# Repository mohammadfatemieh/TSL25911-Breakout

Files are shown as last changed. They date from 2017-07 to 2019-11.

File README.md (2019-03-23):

# TSL25911-Breakout
Breakout with AMS TSL25911 Digital Light Sensor.

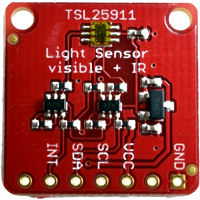
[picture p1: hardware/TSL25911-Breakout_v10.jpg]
TSL25911-Breakout


* [AMS TSL25911](https://ams.com/TSL25911) Light Sensor
* Detects visible and IR light
* Range: 0.5 lux to 88k lux
* TWI/I2C Interface (address 0x29)
* 3.3V - 5V Power Supply and Logic Level
* Open-Source and released under the [Creative Commons Attribution Share-Alike License](https://creativecommons.org/licenses/by-sa/4.0/).
* **[Documentation on learn.watterott.com](https://learn.watterott.com)**

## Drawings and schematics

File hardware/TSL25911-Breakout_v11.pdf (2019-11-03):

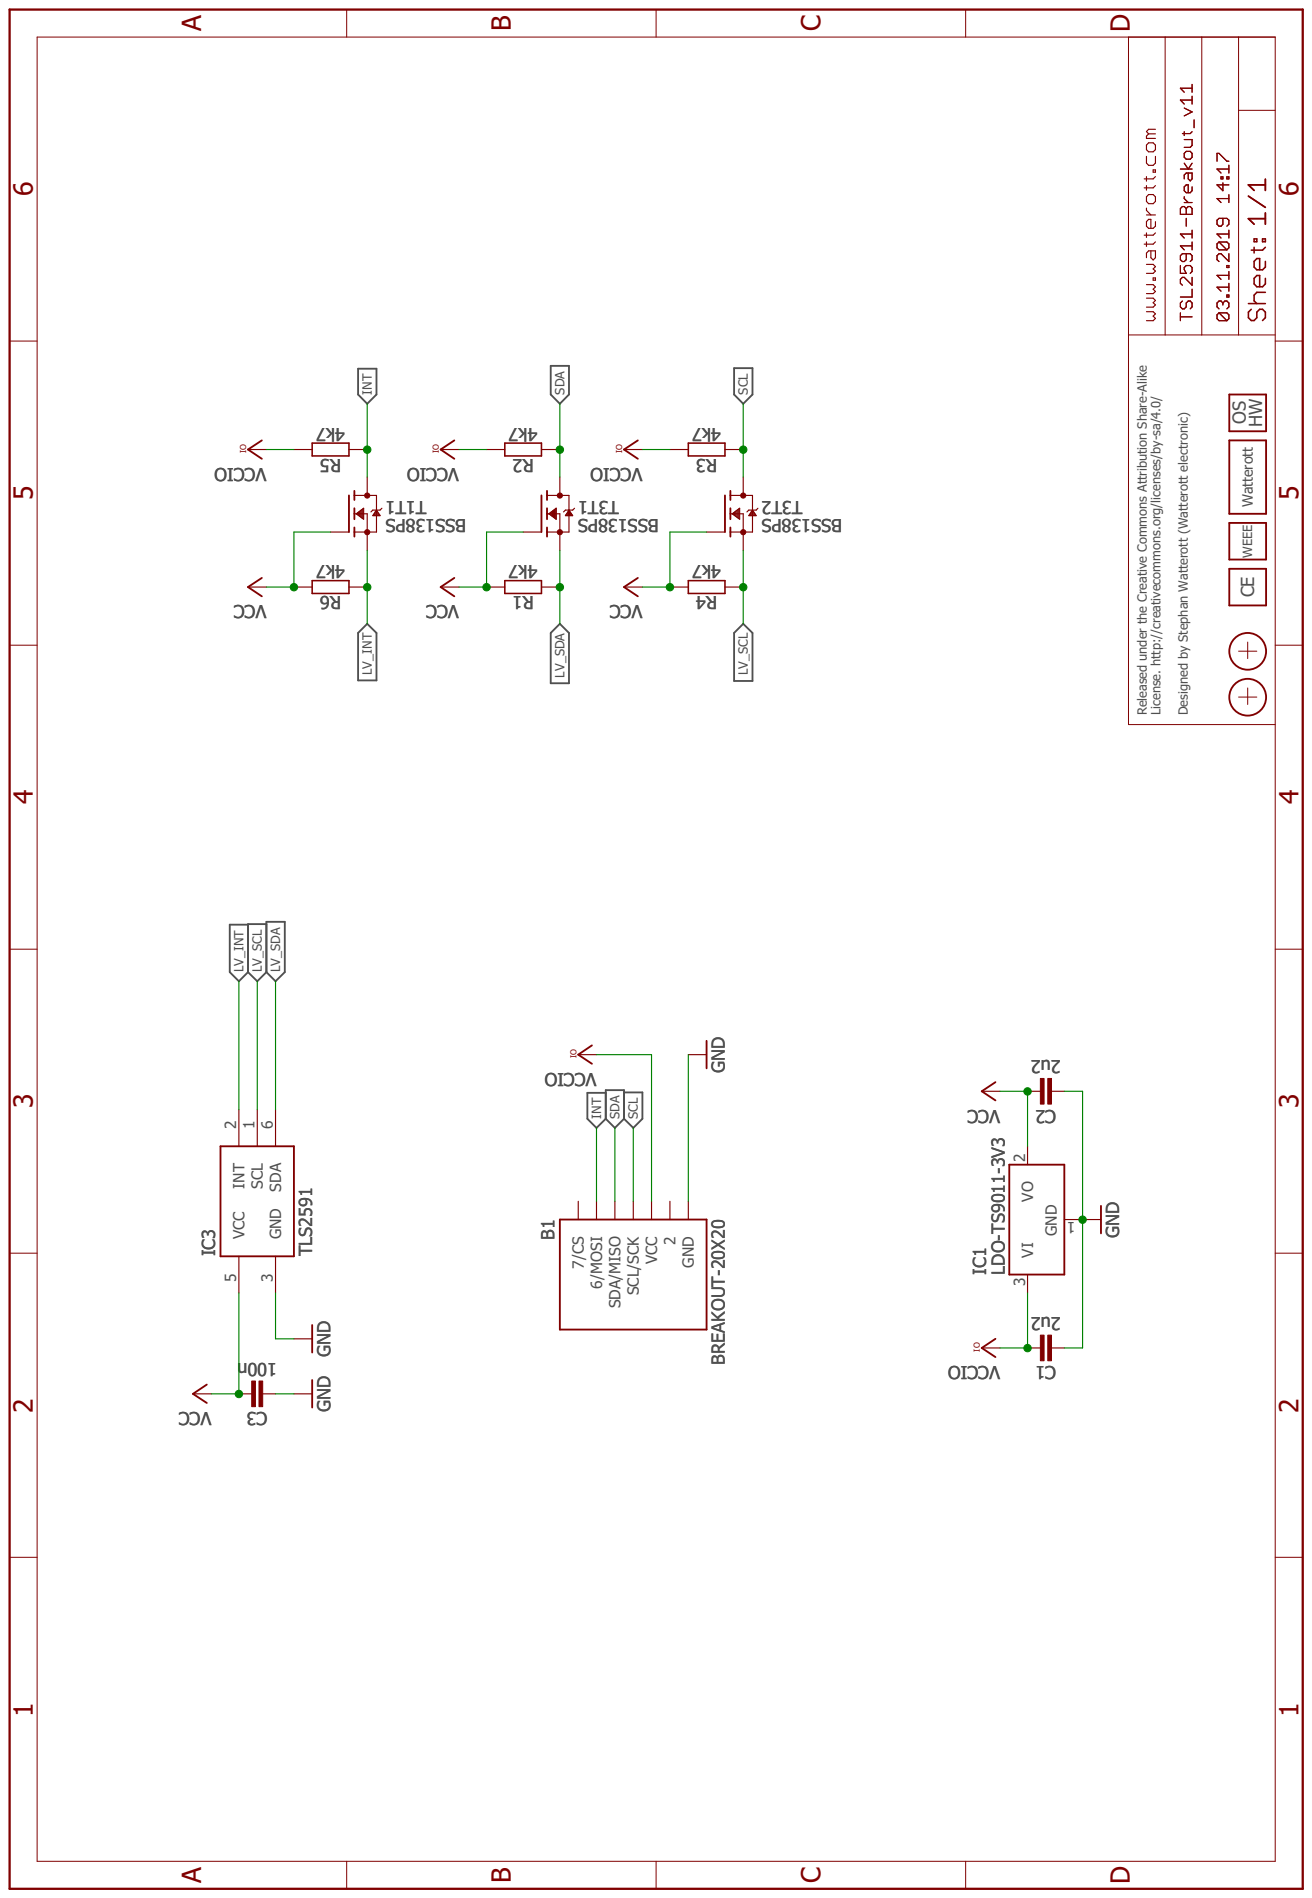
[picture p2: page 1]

Released under the Creative Commons Attribution Share-Alike

License. http://creativecommons.org/licenses/by-sa/4.0/ Designed by Stephan Watterott (Watterott electronic)

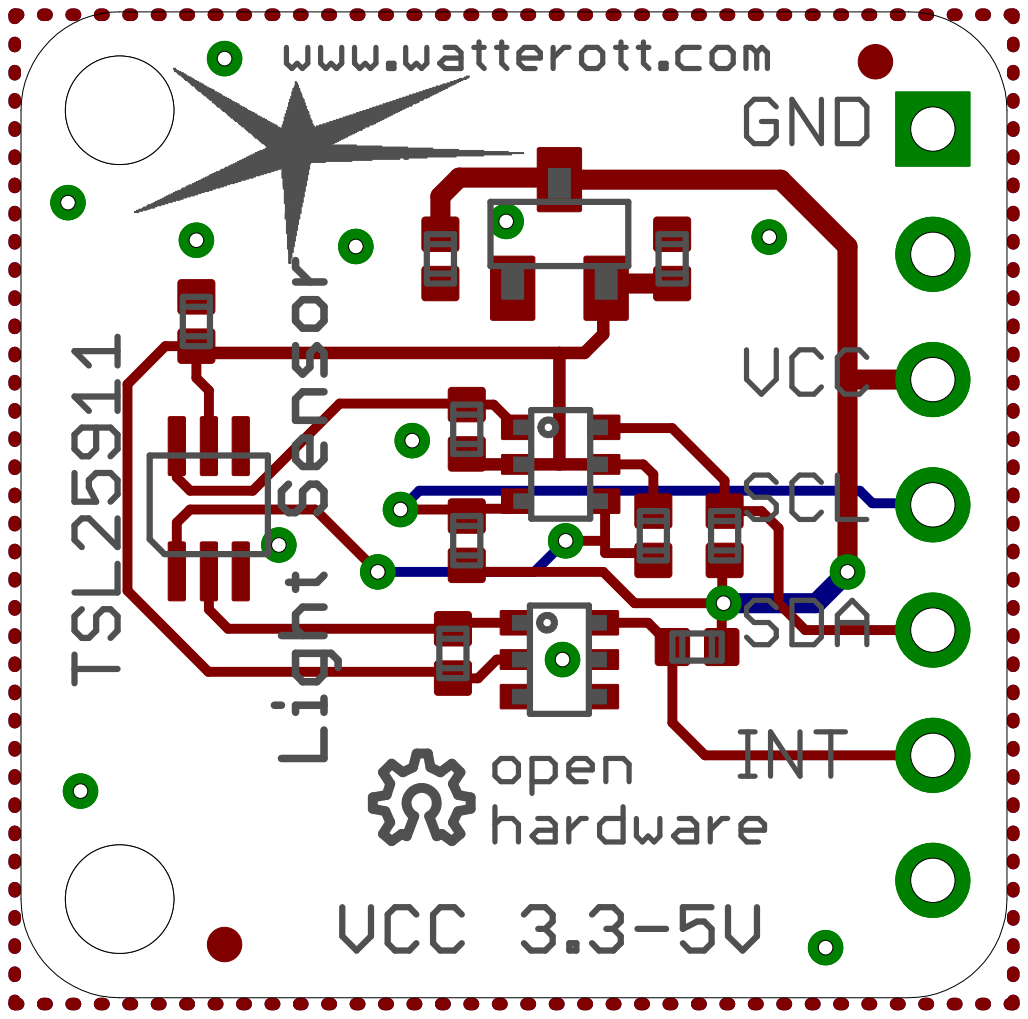
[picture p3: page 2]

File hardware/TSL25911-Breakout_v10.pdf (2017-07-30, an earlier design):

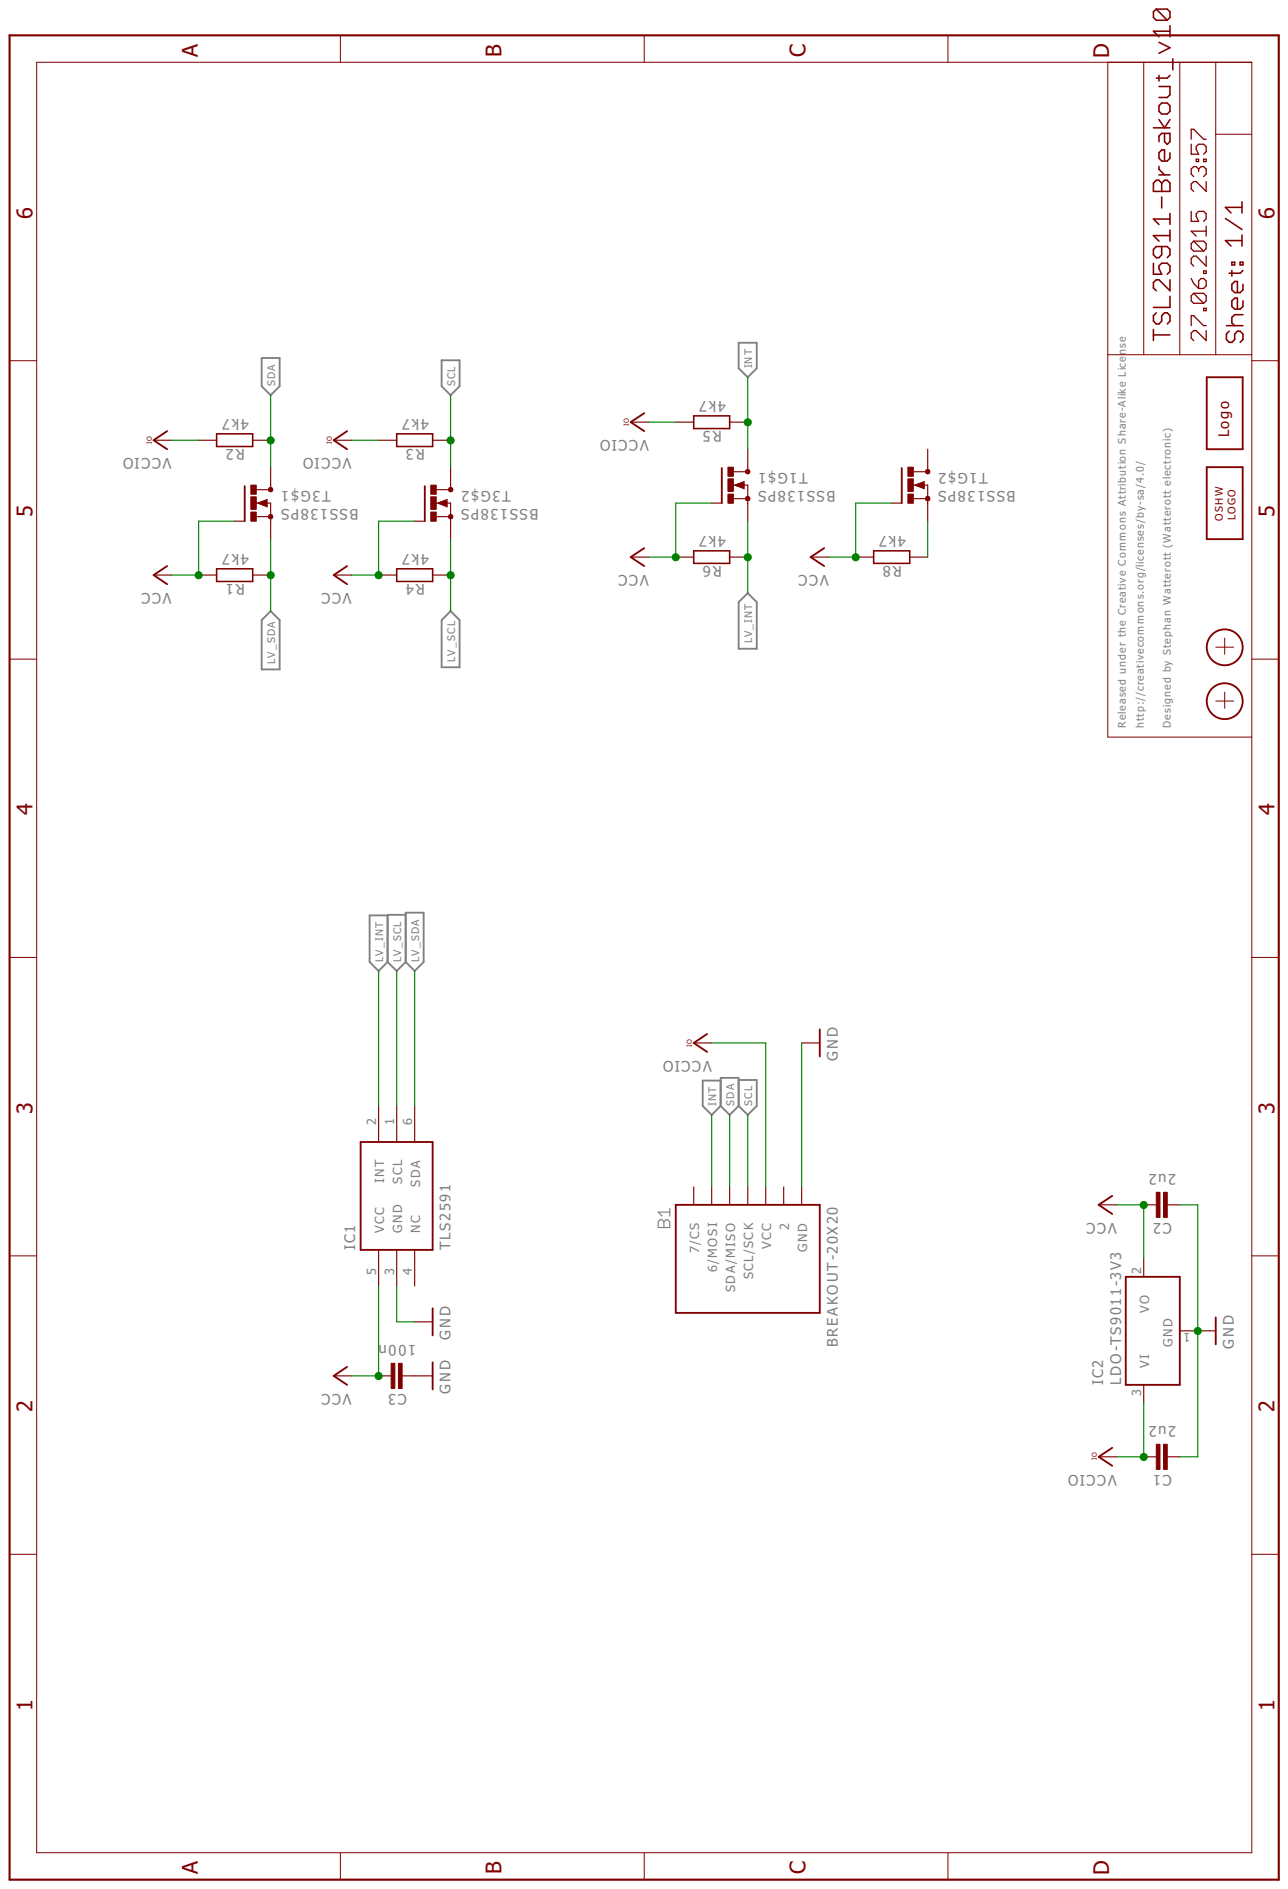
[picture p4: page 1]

Released under the Creative Commons Attribution Share-Alike License http://creativecommons.org/licenses/by-sa/4.0/ Designed by Stephan W atterott (W atterott electronic)

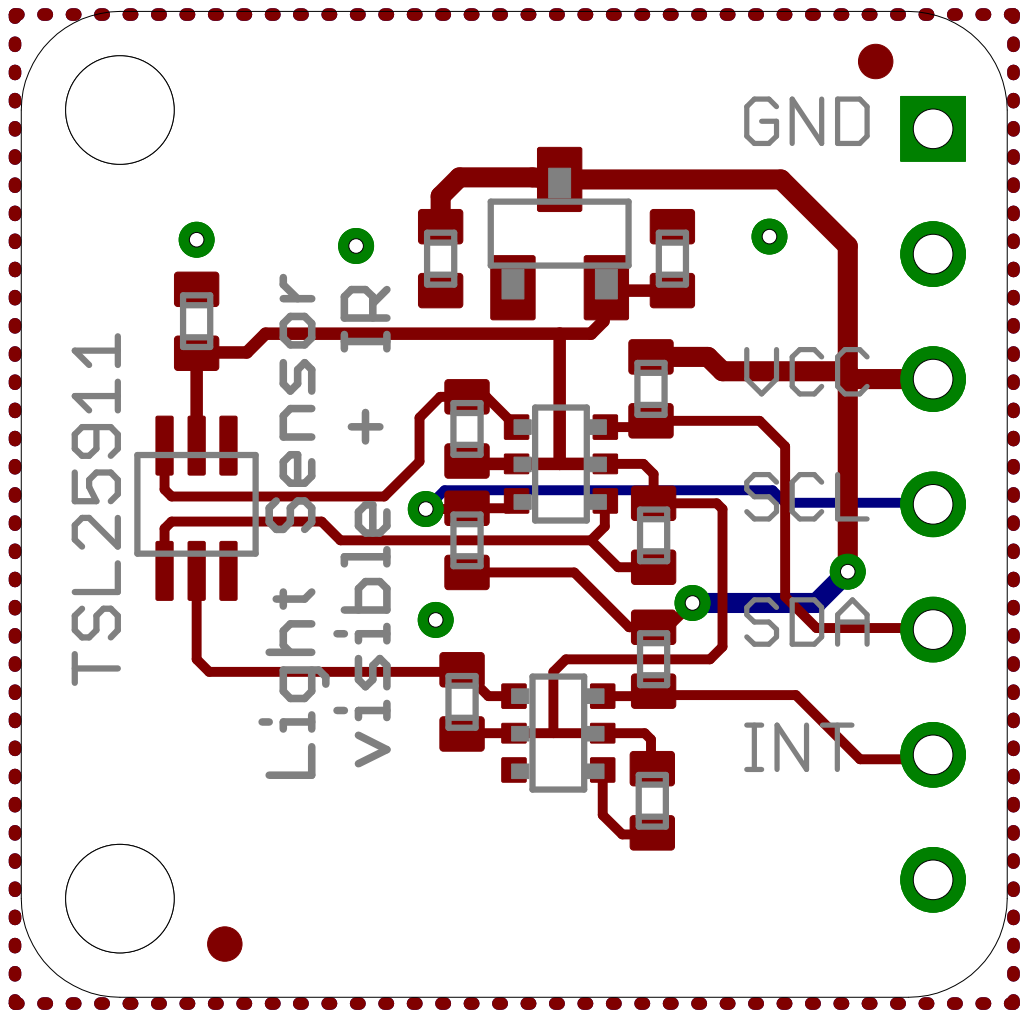
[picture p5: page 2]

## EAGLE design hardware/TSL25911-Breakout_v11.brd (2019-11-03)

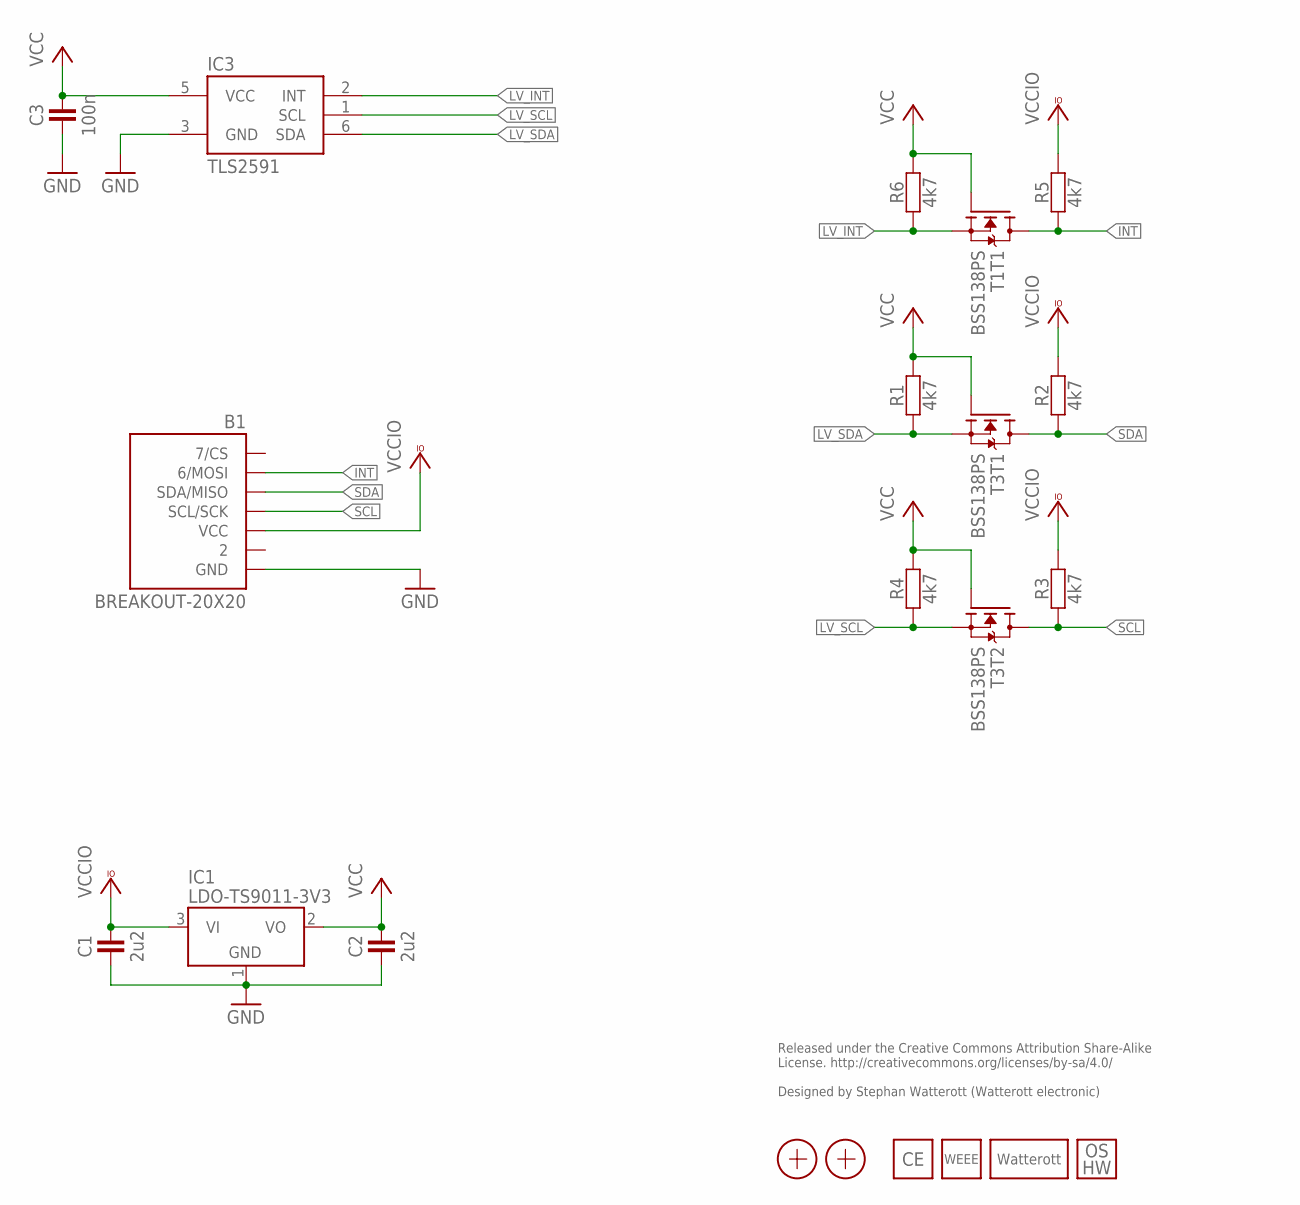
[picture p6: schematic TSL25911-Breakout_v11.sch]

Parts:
B1: BREAKOUT-20X20
C1, C2: 2u2; C0402
C3: 100n; C0402
IC1: LDO-TS9011-3V3; SOT23
IC3: TLS2591; WFDFN6
LOGO3: LOGO_WEEE-4; WEEE_4MM
LOGO4: LOGO_CE-4; CE_4MM
LOGO5: LOGO_SPARK-4; SPARK_4MM
LOGO6: LOGO_OSHW-2; OSHW_2MM
R1, R2, R3, R4, R5, R6: 4k7; C0402
T1, T3: BSS138PS; SOT363
X1, X2: PASSER-07; PASSER_07MM

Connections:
GND: B1.GND, C1.1, C2.1, C3.1, IC1.1 (GND), IC3.3 (GND)
INT: B1.MOSI (6/MOSI), R5.1, T1.6 (D)
LV_INT: IC3.2 (INT), R6.1, T1.1 (S)
LV_SCL: IC3.1 (SCL), R4.1, T3.4 (S)
LV_SDA: IC3.6 (SDA), R1.1, T3.1 (S)
SCL: B1.SCL/SCK, R3.1, T3.3 (D)
SDA: B1.SDA/MISO, R2.1, T3.6 (D)
VCC: C2.2, C3.2, IC1.2 (VO), IC3.5 (VCC), R1.2, R4.2, R6.2, T1.2 (G), T3.2 (G), T3.5 (G)
VCCIO: B1.VCC, C1.2, IC1.3 (VI), R2.2, R3.2, R5.2

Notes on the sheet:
Released under the Creative Commons Attribution Share-Alike License. http://creativecommons.org/licenses/by-sa/4.0/ Designed by Stephan Watterott (Watterott electronic)

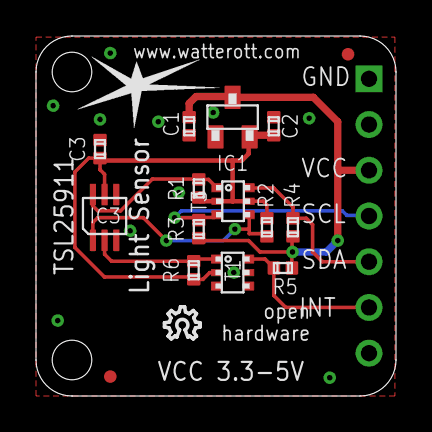
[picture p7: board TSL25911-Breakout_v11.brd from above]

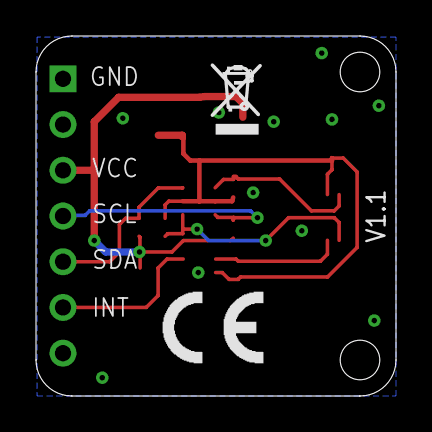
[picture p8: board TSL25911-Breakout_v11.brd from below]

Board: 2 copper layers, 20.0 x 20.0 mm, 20 parts (2 on the bottom side), 9 nets.

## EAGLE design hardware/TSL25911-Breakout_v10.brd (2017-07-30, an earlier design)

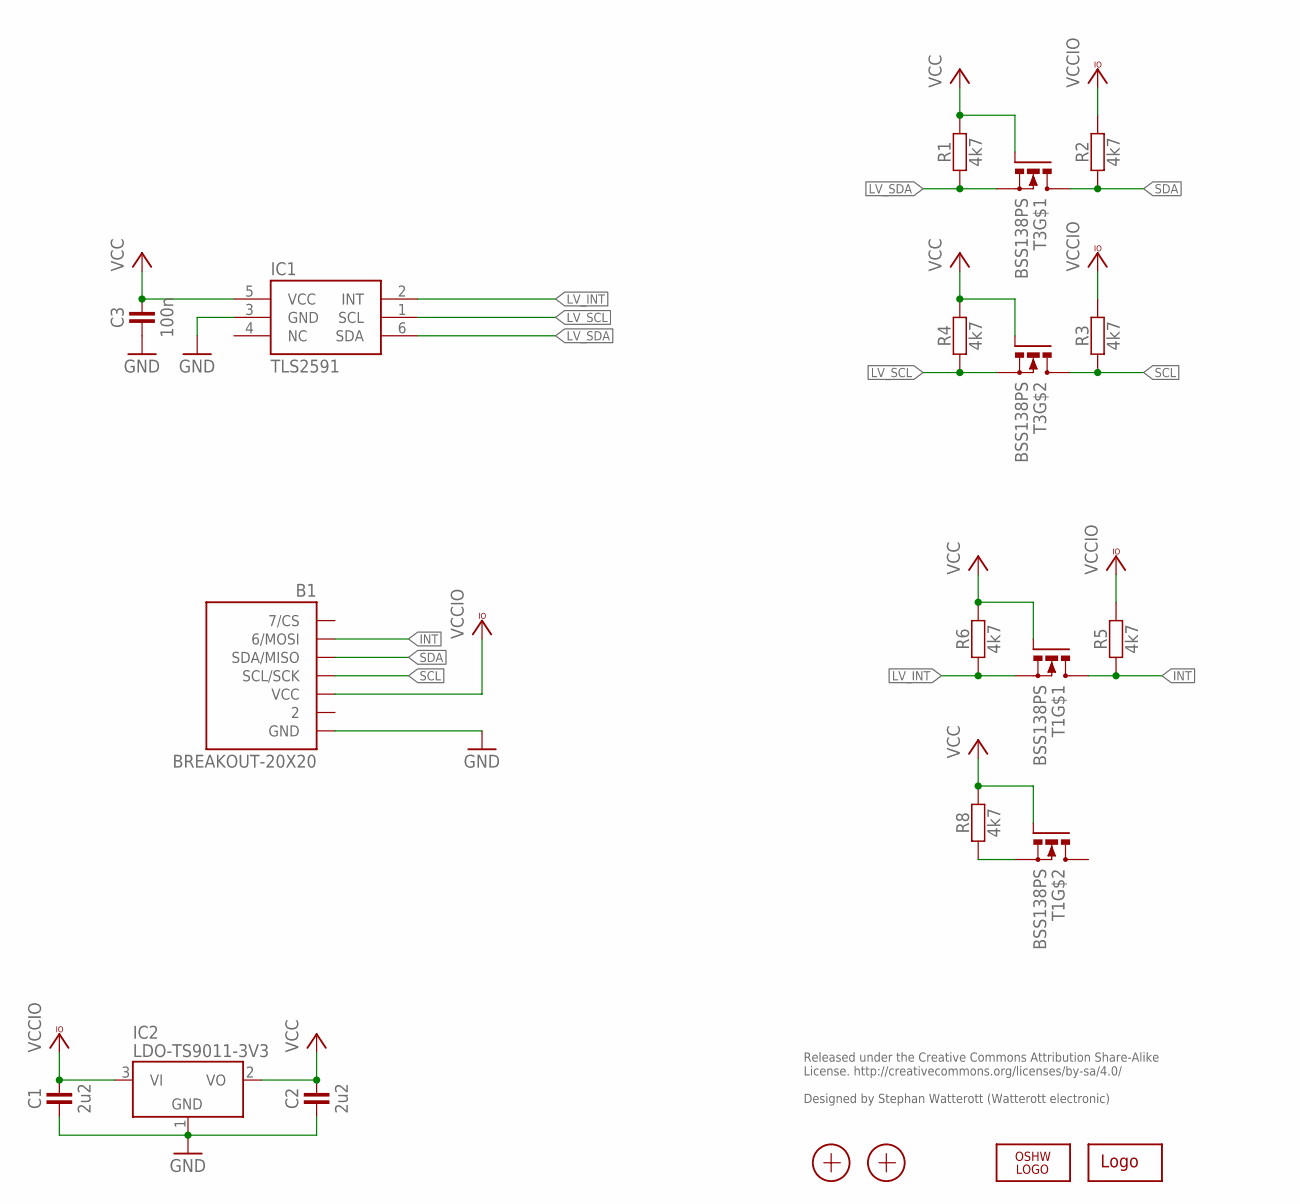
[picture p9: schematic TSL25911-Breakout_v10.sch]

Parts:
B1: BREAKOUT-20X20
C1, C2: 2u2; R0402
C3: 100n; R0402
IC1: TLS2591; WFDFN6
IC2: LDO-TS9011-3V3; SOT23
LOGO1: LOGO-S_PLACE_M; SPARK_TPLACE_M
LOGO2: OSHW_LOGOX0070; OSHW_6X70
R1, R2, R3, R4, R5, R6, R8: 4k7; R0402
T1, T3: BSS138PS; SOT363
X1, X2: PASSER-07; PASSER_07MM

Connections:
GND: B1.GND, C1.1, C2.1, C3.1, IC1.3 (GND), IC2.1 (GND)
INT: B1.MOSI (6/MOSI), R5.1, T1.6 (D)
LV_CSB: R8.1, T1.4 (S)
LV_INT: IC1.2 (INT), R6.1, T1.1 (S)
LV_SCL: IC1.1 (SCL), R4.1, T3.4 (S)
LV_SDA: IC1.6 (SDA), R1.1, T3.1 (S)
SCL: B1.SCL/SCK, R3.1, T3.3 (D)
SDA: B1.SDA/MISO, R2.1, T3.6 (D)
VCC: C2.2, C3.2, IC1.5 (VCC), IC2.2 (VO), R1.2, R4.2, R6.2, R8.2, T1.2 (G), T1.5 (G), T3.2 (G), T3.5 (G)
VCCIO: B1.VCC, C1.2, IC2.3 (VI), R2.2, R3.2, R5.2

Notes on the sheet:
Released under the Creative Commons Attribution Share-Alike License. http://creativecommons.org/licenses/by-sa/4.0/ Designed by Stephan Watterott (Watterott electronic)

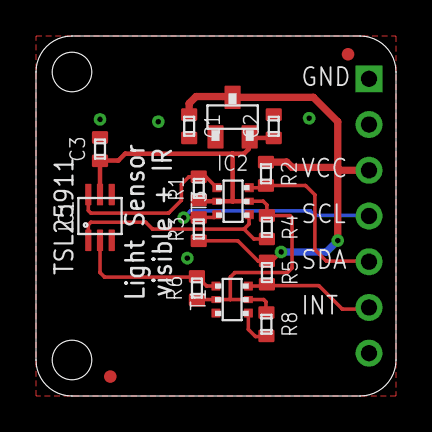
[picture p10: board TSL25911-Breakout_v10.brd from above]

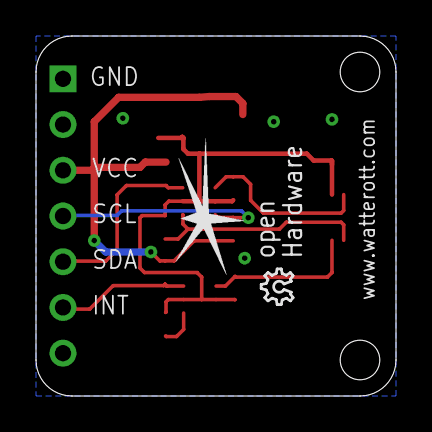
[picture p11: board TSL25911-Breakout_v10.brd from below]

Board: 2 copper layers, 20.0 x 20.0 mm, 19 parts (2 on the bottom side), 10 nets.

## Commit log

2019-11-03 added rev 1.1
    [TSL25911-Breakout_v11.brd, TSL25911-Breakout_v11.sch]
2019-11-03 updated layout
    [TSL25911-Breakout_v11.brd]
